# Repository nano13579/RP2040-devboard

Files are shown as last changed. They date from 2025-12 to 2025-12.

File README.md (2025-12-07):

# an rp2040 dev board

This is a dev board based upon the RP2040 microcontroller, a 32-bit dual-core ARM Cortex-M0+. This board comes with 16mb of flash memory, a 12 MHz crystal oscillator, a USB-C for power with a Low-Dropout Regulator, and light sensing capabilites enabled using a TSL25911FN. I made this because I was interested in the use of various components for general RP2040 based boards. This was also my first time making a microcontoller in general, and I learned much about the purpose of various IC's and passive components in the process! 

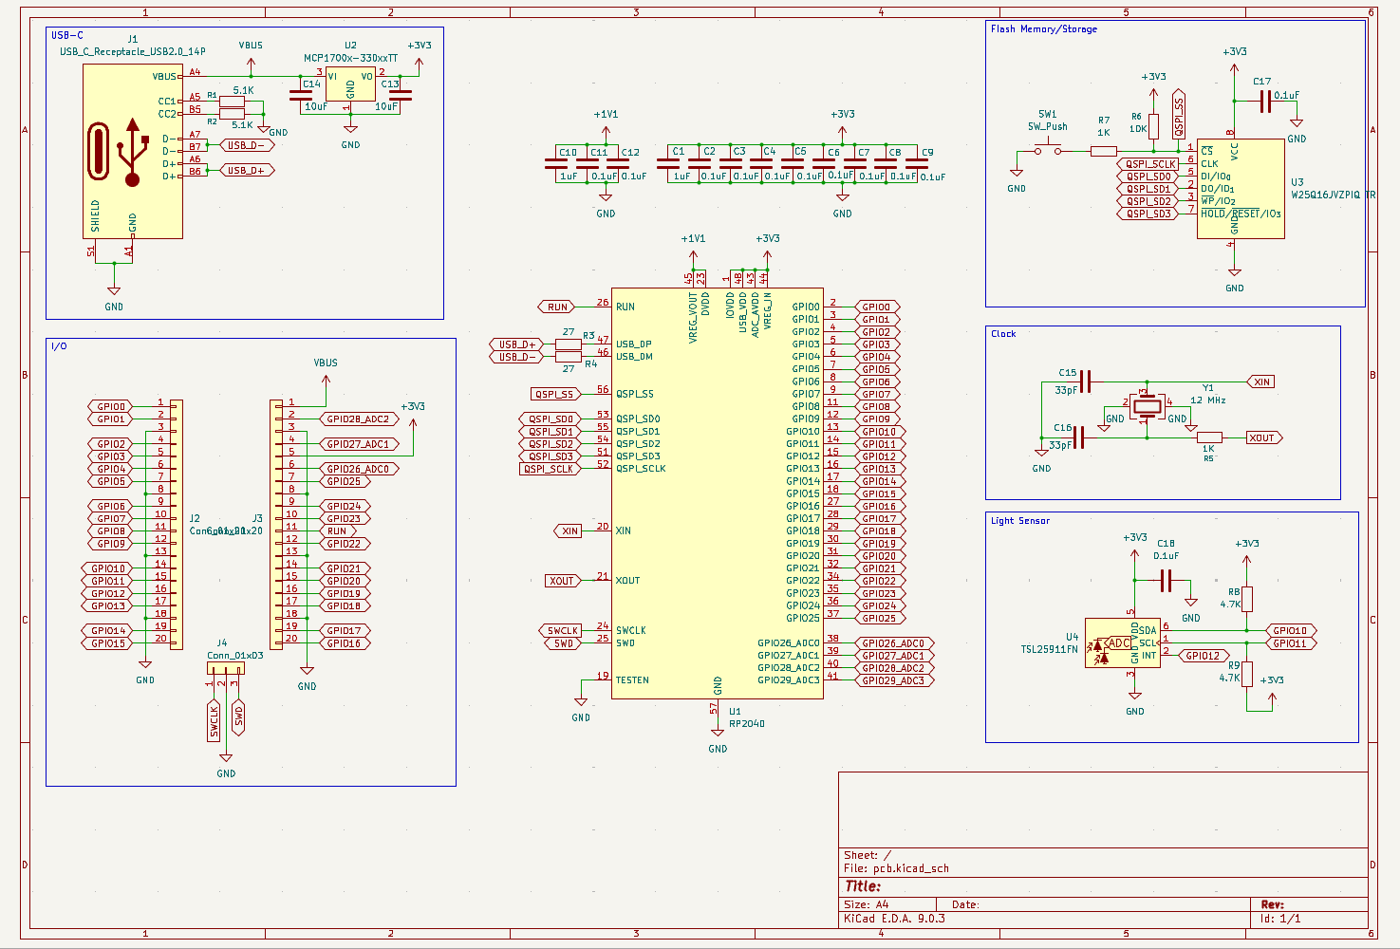
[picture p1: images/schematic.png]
Schematic:


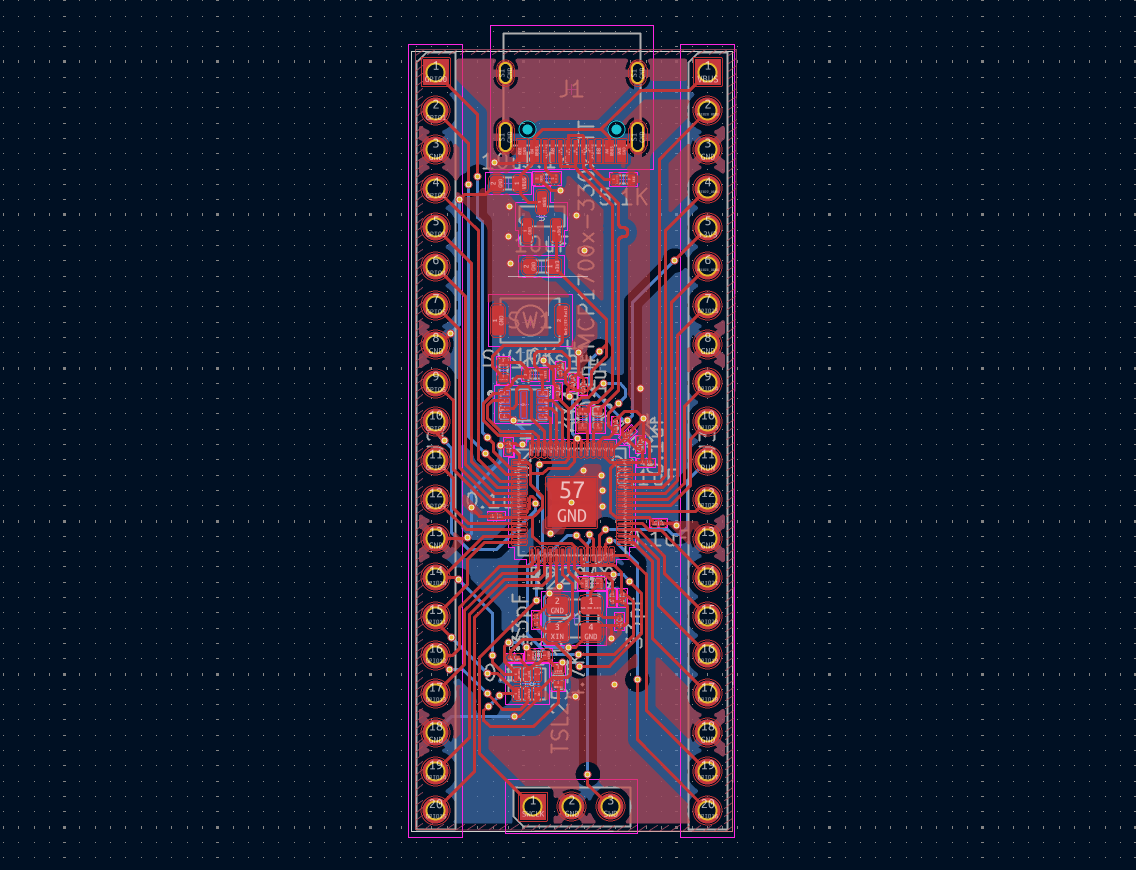
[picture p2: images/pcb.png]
PCB:


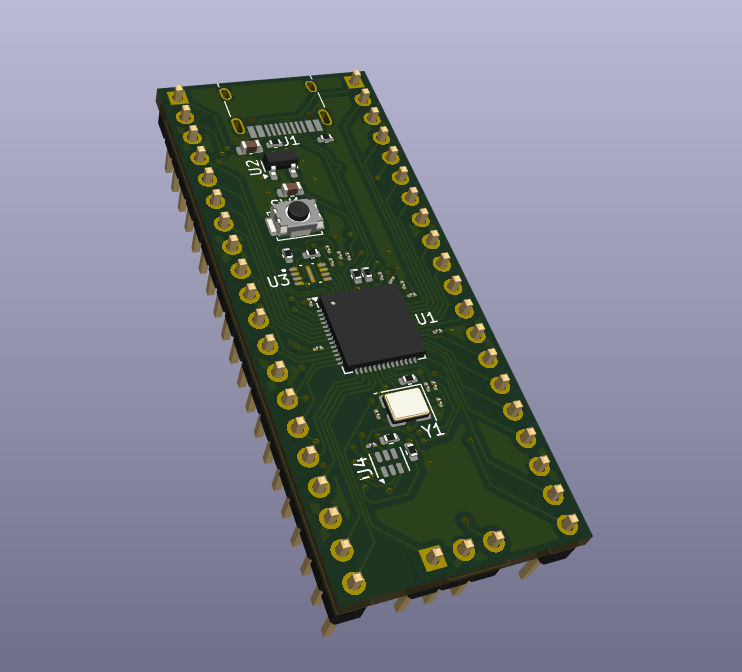
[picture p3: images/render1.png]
Render:


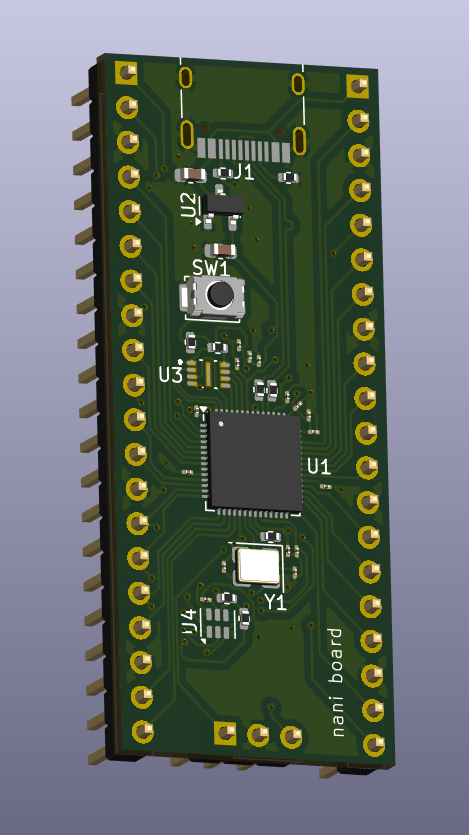
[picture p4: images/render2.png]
Render:


| Item | Quantity | Product Link | Cost |
|---|---|---|---|
| 1uF 0402 Cap | 2 | [link](https://jlcpcb.com/partdetail/SamsungElectro-CL05A105KA5NQNC/C52923) | $0.01 |
| 0.1uF 0402 Cap | 12 | [link](https://jlcpcb.com/partdetail/SamsungElectro-CL05B104KO5NNNC/C1525) | $0.01 |
| 33pF 0402 Cap | 2 | [link](https://jlcpcb.com/partdetail/TaiyoYuden-EMK042CH330JCW/C783027) | $0.01 |
| 10uF 0603 Cap | 2 | [link](https://jlcpcb.com/partdetail/2043-CL10A106MQ8NNNC/C1691) | $0.01 |
| 4.7K 0402 Resistor | 2 | [link](https://jlcpcb.com/partdetail/26643-0402WGF4701TCE/C25900) | $0.01 |
| 1K 0402 Resistor | 2 | [link](https://jlcpcb.com/partdetail/YAGEO-RC0100JR071KL/C327020) | $0.01 |
| 27 0402 Resistor | 2 | [link](https://jlcpcb.com/partdetail/YAGEO-RC0100JR0727RL/C850592) | $0.01 |
| 5.1K 0402 Resistor | 2 | [link](https://jlcpcb.com/partdetail/TyoHM-RMC04025_1K1N/C325521) | $0.01 |
| 10K 0402 Resistor | 1 | [link](https://jlcpcb.com/partdetail/259835-0105WHF1002TDE/C270305) | $0.01 |
| MCP1700x-330xxTT | 1 | [link](https://jlcpcb.com/partdetail/MicrochipTech-MCP1700T_3302ETT/C39051) | $0.39 |
| RP2040 | 1 | [link](https://jlcpcb.com/partdetail/RaspberryPi-RP2040/C2040) | $0.92 |
| W25Q16JVZPIQ TR | 1 | [link](https://jlcpcb.com/partdetail/WinbondElec-W25Q16JVZPIQTR/C2456208) | $0.90 |
| TSL25911FN | 1 | [link](https://jlcpcb.com/partdetail/AMS-TSL25911FN/C176812) | $1.74 |
| 12 MHz Crystal | 1 | [link](https://jlcpcb.com/partdetail/SeikoEpson-X1G0044510028/C32540) | $0.80 |
| Conn_01x20 (Pin Header) | 2 | [link](https://jlcpcb.com/partdetail/51993-2_54_1_20PStraightpin/C50981) | $0.21 |
| Conn_01x03 (Pin Header) | 1 | [link](https://jlcpcb.com/partdetail/50265-2_54_13PPin/C49257) | $0.02 |
| USB-C Receptacle | 1 | [link](https://jlcpcb.com/partdetail/Korean_HropartsElec-TYPE_C_31_M12/C165948) | $0.17 |
| Switch | 1 | [link](https://jlcpcb.com/partdetail/CK-KMR241GLFS/C221682) | $0.81 |

Total Parts Cost + PCBA + JLC Shipping = $13.83 + $3.20 + $24.26 = ($33.51 + taxes + feeder fees)*

*no need for grant - paying everything out of pocket

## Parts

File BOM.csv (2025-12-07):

Id | Designator | Footprint | Quantity | Comment | Supplier and ref
1 | C1,C10 | C_01005_0402Metric | 2 | 1uF
2 | C2,C3,C4,C5,C6,C7,C8,C9,C11,C12,C17,C18 | C_01005_0402Metric | 12 | 0.1uF
3 | C15,C16 | C_01005_0402Metric | 2 | 33pF
4 | J1 | USB_C_Receptacle_HRO_TYPE-C-31-M-12 | 1 | USB_C_Receptacle_USB2.0_14P
5 | R8,R9 | R_0402_1005Metric | 2 | 4.7K
6 | U1 | QFN-56-1EP_7x7mm_P0.4mm_EP3.2x3.2mm | 1 | RP2040
7 | U3 | IC_W25Q16JVUXIQ_TR | 1 | W25Q16JVZPIQ TR
8 | U4 | AMS_TSL25911FN | 1 | TSL25911FN
9 | J2,J3 | PinHeader_1x20_P2.54mm_Vertical | 2 | Conn_01x20
10 | J4 | PinHeader_1x03_P2.54mm_Vertical | 1 | Conn_01x03
11 | R7,R5 | R_0402_1005Metric | 2 | 1K
12 | C13,C14 | C_0603_1608Metric | 2 | 10uF
13 | R3,R4 | R_0402_1005Metric | 2 | 27
14 | R2,R1 | R_0402_1005Metric | 2 | 5.1K
15 | SW1 | SW_Push_SPST_NO_Alps_SKRK | 1 | SW_Push
16 | R6 | R_0402_1005Metric | 1 | 10K
17 | U2 | SOT-23 | 1 | MCP1700x-330xxTT
18 | Y1 | Crystal_SMD_3225-4Pin_3.2x2.5mm | 1 | 12 MHz

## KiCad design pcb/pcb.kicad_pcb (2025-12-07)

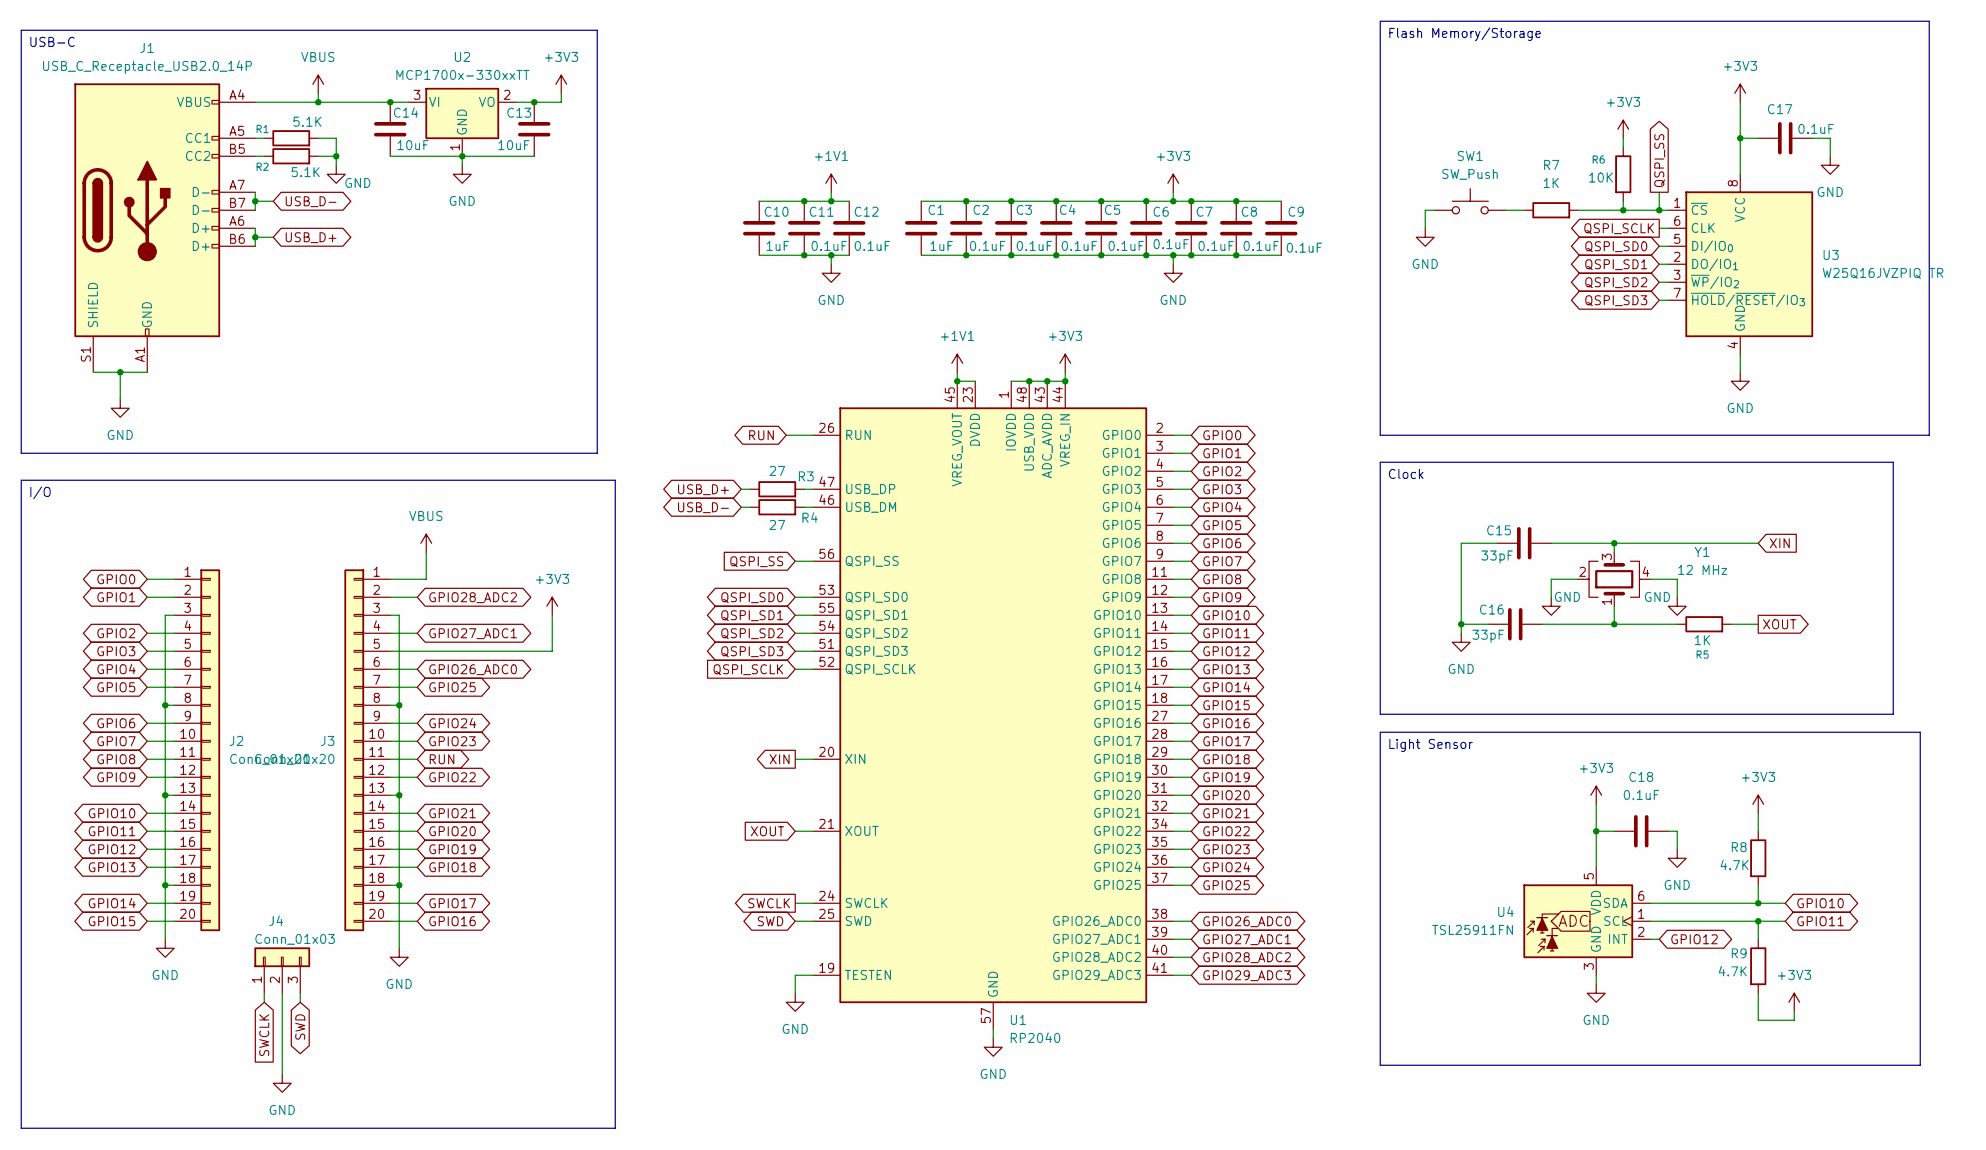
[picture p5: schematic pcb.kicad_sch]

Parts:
C1, C10: 1uF; C_01005_0402Metric
C2, C3, C4, C5, C6, C7, C8, C9, C11, C12, C17, C18: 0.1uF; C_01005_0402Metric
C13, C14: 10uF; C_0603_1608Metric
C15, C16: 33pF; C_01005_0402Metric
J1: USB_C_Receptacle_USB2.0_14P; USB_C_Receptacle_HRO_TYPE-C-31-M-12
J2, J3: Conn_01x20; PinHeader_1x20_P2.54mm_Vertical
J4: Conn_01x03; PinHeader_1x03_P2.54mm_Vertical
R1, R2: 5.1K; R_0402_1005Metric
R3, R4: 27; R_0402_1005Metric
R5, R7: 1K; R_0402_1005Metric
R6: 10K; R_0402_1005Metric
R8, R9: 4.7K; R_0402_1005Metric
SW1: SW_Push; SW_Push_SPST_NO_Alps_SKRK
U1: RP2040; QFN-56-1EP_7x7mm_P0.4mm_EP3.2x3.2mm
U2: MCP1700x-330xxTT; SOT-23
U3: W25Q16JVZPIQ TR; IC_W25Q16JVUXIQ_TR
U4: TSL25911FN; AMS_TSL25911FN
Y1: 12 MHz; Crystal_SMD_3225-4Pin_3.2x2.5mm

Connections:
+1V1: C10.1, C11.1, C12.1, U1.23 (DVDD), U1.45 (VREG_VOUT), U1.50 (DVDD)
+3V3: C1.1, C2.1, C3.1, C4.1, C5.1, C6.1, C7.1, C8.1, C9.1, C13.1, C17.1, C18.2, J3.5, R6.1, R8.1, R9.2, U1.1 (IOVDD), U1.10 (IOVDD), U1.22 (IOVDD), U1.33 (IOVDD), U1.42 (IOVDD), U1.43 (ADC_AVDD), U1.44 (VREG_IN), U1.48 (USB_VDD), U1.49 (IOVDD), U2.2 (VO), U3.8 (VCC), U4.5 (VDD)
GND: C1.2, C2.2, C3.2, C4.2, C5.2, C6.2, C7.2, C8.2, C9.2, C10.2, C11.2, C12.2, C13.2, C14.2, C15.1, C16.1, C17.2, C18.1, J1.A1 (GND), J1.A12 (GND), J1.B1 (GND), J1.B12 (GND), J1.S1 (SHIELD), J2.3, J2.8, J2.13, J2.18, J3.3, J3.8, J3.13, J3.18, J4.2, R1.2, R2.2, SW1.1, U1.19 (TESTEN), U1.57 (GND), U2.1 (GND), U3.4 (GND), U4.3 (GND), Y1.2, Y1.4
GPIO0: J2.1, U1.2 (GPIO0)
GPIO1: J2.2, U1.3 (GPIO1)
GPIO2: J2.4, U1.4 (GPIO2)
GPIO3: J2.5, U1.5 (GPIO3)
GPIO4: J2.6, U1.6 (GPIO4)
GPIO5: J2.7, U1.7 (GPIO5)
GPIO6: J2.9, U1.8 (GPIO6)
GPIO7: J2.10, U1.9 (GPIO7)
GPIO8: J2.11, U1.11 (GPIO8)
GPIO9: J2.12, U1.12 (GPIO9)
GPIO10: J2.14, R8.2, U1.13 (GPIO10), U4.6 (SDA)
GPIO11: J2.15, R9.1, U1.14 (GPIO11), U4.1 (SCL)
GPIO12: J2.16, U1.15 (GPIO12), U4.2 (INT)
GPIO13: J2.17, U1.16 (GPIO13)
GPIO14: J2.19, U1.17 (GPIO14)
GPIO15: J2.20, U1.18 (GPIO15)
GPIO16: J3.20, U1.27 (GPIO16)
GPIO17: J3.19, U1.28 (GPIO17)
GPIO18: J3.17, U1.29 (GPIO18)
GPIO19: J3.16, U1.30 (GPIO19)
GPIO20: J3.15, U1.31 (GPIO20)
GPIO21: J3.14, U1.32 (GPIO21)
GPIO22: J3.12, U1.34 (GPIO22)
GPIO23: J3.10, U1.35 (GPIO23)
GPIO24: J3.9, U1.36 (GPIO24)
GPIO25: J3.7, U1.37 (GPIO25)
GPIO26_ADC0: J3.6, U1.38 (GPIO26_ADC0)
GPIO27_ADC1: J3.4, U1.39 (GPIO27_ADC1)
GPIO28_ADC2: J3.2, U1.40 (GPIO28_ADC2)
GPIO29_ADC3: U1.41 (GPIO29_ADC3)
unnamed: C16.2, R5.1, Y1.1
unnamed: J1.A5 (CC1), R1.1
unnamed: J1.B5 (CC2), R2.1
unnamed: R7.1, SW1.2
unnamed: R4.2, U1.46 (USB_DM)
unnamed: R3.2, U1.47 (USB_DP)
QSPI_SCLK: U1.52 (QSPI_SCLK), U3.6 (CLK)
QSPI_SD0: U1.53 (QSPI_SD0), U3.5 (DI/IO_{0})
QSPI_SD1: U1.55 (QSPI_SD1), U3.2 (DO/IO_{1})
QSPI_SD2: U1.54 (QSPI_SD2), U3.3 (~WP/IO_{2})
QSPI_SD3: U1.51 (QSPI_SD3), U3.7 (~HOLD/~RESET/IO_{3})
QSPI_SS: R6.2, R7.2, U1.56 (QSPI_SS), U3.1 (~CS)
RUN: J3.11, U1.26 (RUN)
SWCLK: J4.1, U1.24 (SWCLK)
SWD: J4.3, U1.25 (SWD)
USB_D+: J1.A6 (D+), J1.B6 (D+), R3.1
USB_D-: J1.A7 (D-), J1.B7 (D-), R4.1
VBUS: C14.1, J1.A4 (VBUS), J1.A9 (VBUS), J1.B4 (VBUS), J1.B9 (VBUS), J3.1, U2.3 (VI)
XIN: C15.2, U1.20 (XIN), Y1.3
XOUT: R5.2, U1.21 (XOUT)

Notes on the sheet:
Clock
Light Sensor
USB-C
I/O
Flash Memory/Storage

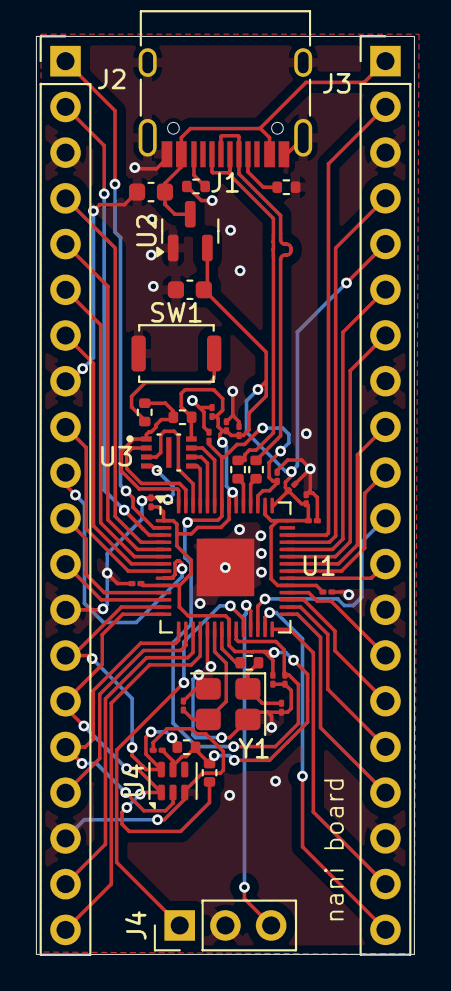
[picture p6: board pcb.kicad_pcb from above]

Board: 2 copper layers, 21.0 x 51.0 mm, 37 parts (0 on the bottom side), 52 nets.

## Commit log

2025-12-05 update schematic
    [pcb.kicad_pcb, pcb.kicad_sch]
2025-12-06 update pcb
    [pcb.kicad_pcb, pcb.kicad_sch]
2025-12-07 update pcb, readme, BOM
    [pcb-B_Cu.gbr, pcb-B_Mask.gbr, pcb-B_Paste.gbr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]
2025-12-07 update README, silkscreen
    [pcb.kicad_pcb]
